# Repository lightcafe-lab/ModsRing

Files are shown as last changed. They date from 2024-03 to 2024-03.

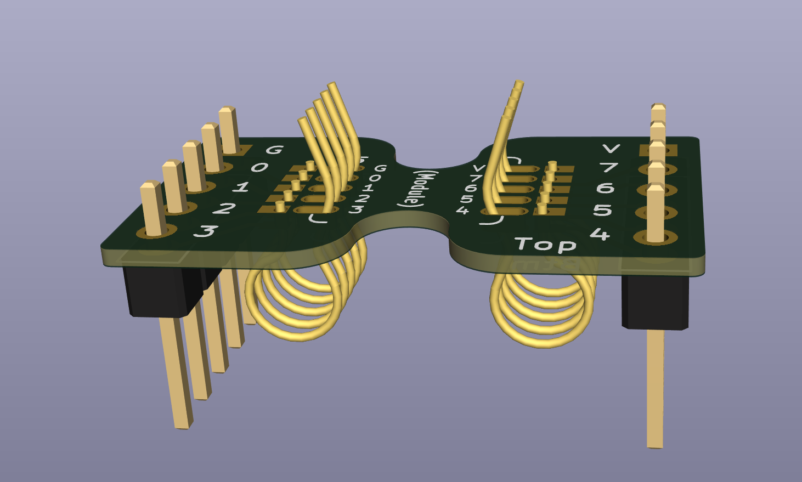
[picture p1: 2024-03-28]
smdMod/options/127to254-pitch-convert/images.png

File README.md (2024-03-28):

# ModsRing
ModsRingは**smdMod**を使用したモジュール式のスマートリングです<br>
**smdMod** = **S**urface **M**ount **D**evice **Mod**ule（表面実装式の基板モジュール）の略称です<br><br>
LIGHTCAFE LAB ModsRing 作品ページ<br>
https://lab.lightcafe.co.jp/work/modsring<br>
LIGHTCAFE LAB smdMod 作品ページ<br>
https://lab.lightcafe.co.jp/work/smdmod<br>

MODSRING
## firmware
ModsRingに書き込むArduinoのサンプルスケッチです<br>

*ble-finger-mouse*<br>
PCとBluetooth接続すると指マウスになります<br>
## hardware
ModsRing付属のハードウェアです<br>

*modsring.stl*<br>
リング形状のカバーです。22号リング(内径:20ｍｍ)のサイズになっています<br>
市販の3Dプリンタで作成できます<br>

## smdMod
KiCad (v6.0.10)を使用した回路図と基板図です<br>

*base-board/mr-base*<br>
ModsRingのベース基板です<br>

*modules/mcu-and-power*<br>
MCUと電源モジュール<br>
・MCUモジュール：ISP1807(nRF52840）をBGAピッチ（1.00mmピッチ、Φ0.6mm）に変換<br>
・電源モジュール1：3.3Vレギュレータ+LiPo充電+LiPo/USB電源切替<br>
・電源モジュール2：LiPoバッテリゲージ+LiPo電池接続パッド<br>

*modules/switch-led-and-accel-sensor*<br>
GPIOとセンサモジュール<br>
・拡張モジュール1（フルカラーLED＋スイッチ）<br>
・拡張モジュール2（加速度センサ）<br>

*modules/usb-interface*<br>
USB I/F用の基板<br>
・基板1（USB-C）<br>
・基板2（USBピン）<br>

*options/127to254-pitch-convert*<br>
モジュールのピッチ変換基板<br>
・1.27mmピッチ_10ピンを2.54mmピッチ_10ピンに変換します<br>

## ライセンスについて
この 作品 は <a rel="license" href="https://creativecommons.org/licenses/by-sa/4.0/deed.ja">クリエイティブ・コモンズ 表示 - 継承 4.0 国際 ライセンス</a>の下に提供されています<br>
<br />

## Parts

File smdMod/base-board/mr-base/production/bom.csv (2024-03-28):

Designator | Footprint | Quantity | Value | LCSC Part #
J1 | if-8080-mcu-v1-for-board | 1 | bga_foot_8*8_1mm_pitch
J2 | pad_1x04_P1.27mm_usbc_mount | 1 | Conn_01x05
J3 | pad_1x04_P1.27mm | 1 | Conn_01x04
J4, J5 | if-8080-10pin-mount-free-pin | 2 | if_8080
J6, J7 | if-8080-10pin-mount-HAT | 2 | if_8080
J8 | pad_1x02_P1.27mm | 1 | Conn_01x02

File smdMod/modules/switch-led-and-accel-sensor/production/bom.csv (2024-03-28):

Designator | Footprint | Quantity | Value | LCSC Part #
C1, C3 | 0402 | 2 | 0.1uF
C2 | 0603 | 1 | 10uF
D1 | LED_APTF1616LSEEZGKQBKC | 1 | APTF1616LSEEZGKQBKC
IC1 | LIS3DH | 1 | LIS3DH
J1, J2 | hachi-8080-10pin-castle | 2 | pin_0205_CCW
R1, R5, R6, R7, R8 | 0402 | 5 | 10k
R2 | 0402 | 1 | 1k
R3, R4 | 0402 | 2 | 330
SW1 | 435151014846 | 1 | 435151014846-SW

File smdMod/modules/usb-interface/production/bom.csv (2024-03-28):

Designator | Footprint | Quantity | Value | LCSC Part #
CN1 | USB-C_PCBPLUG | 1 | CON_USB-CPCBPLUG
J1 | pad_1x04_P1.27mm_usbc | 1 | Conn_01x04
J2 | pad_1x04_P1.27mm_usbc_with_hole | 1 | Conn_01x04
PL1 | 0603 | 1 | 0ZCM0003FF2G
R3, R4 | 0402 | 2 | 5.1k

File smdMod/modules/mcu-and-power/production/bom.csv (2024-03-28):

Designator | Footprint | Quantity | Value | LCSC Part #
C1 | 402 | 1 | 0.1uF
C2, C3, C5, C6 | 201 | 4 | 2.2uF
C4 | 201 | 1 | 0.1uF
D1 | NSR05T40XV2 | 1 | NSR05T40XV2
IC1 | MAX17048G-L | 1 | MAX17048G
IC2 | MCP73832-2ACIMC | 1 | MCP73832-2ACI-MC
IC3 | MIC5514-3.3YMT-TR | 1 | MIC5514-3.3YMT-TR
IC4 | ISP1807-LR-RS | 1 | ISP1807-LR-RS
PL1 | 603 | 1 | 0ZCM0003FF2G
Q1 | SSM3j36FS | 1 | Q_PMOS_GSD
R1, R2 | 402 | 2 | 10k
R3 | 201 | 1 | 18k
R4 | 201 | 1 | 100k

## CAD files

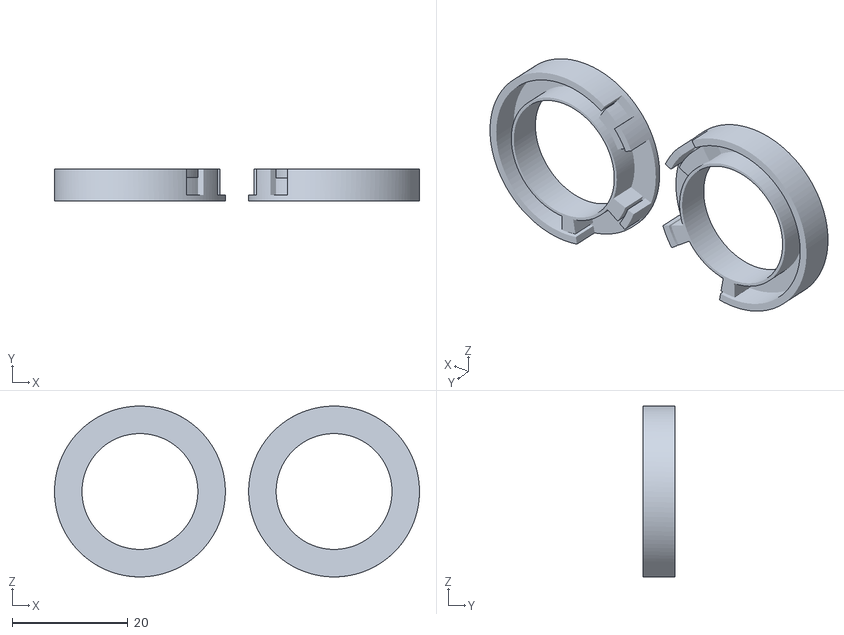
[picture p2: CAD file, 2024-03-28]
hardware/modsring.stl
63.0 x 5.51 x 29.5

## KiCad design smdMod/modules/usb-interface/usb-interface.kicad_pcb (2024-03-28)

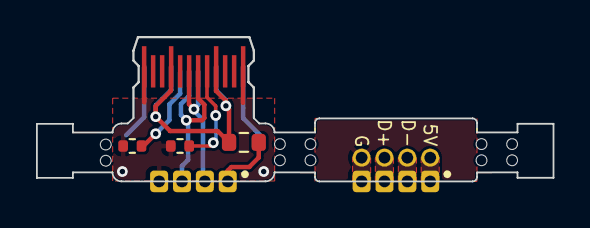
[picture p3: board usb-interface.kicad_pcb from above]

Board: 2 copper layers, 28.7 x 8.0 mm, 6 parts (1 on the bottom side), 7 nets.

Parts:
CN1: CON_USB-CPCBPLUG; USB-C_PCBPLUG
J1: Conn_01x04; pad_1x04_P1.27mm_usbc
J2: Conn_01x04; pad_1x04_P1.27mm_usbc_with_hole
PL1: 0ZCM0003FF2G; R_0603_1608Metric
R3, R4: 5.1k; R_0402_1005Metric_nosilk

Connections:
+5V: J1.1, PL1.2
/USBD+: CN1.P$A6 (D+1), CN1.P$B6 (D+2), J1.3
/USBD-: CN1.P$A7 (D-1), CN1.P$B7 (D-2), J1.2
GNDA: CN1.P$A1 (GND1), CN1.P$A12 (GND2), CN1.P$B1 (GND3), CN1.P$B12 (GND4), J1.4, R3.2, R4.2
unnamed: CN1.P$A5 (CC1), R3.1
unnamed: CN1.P$B5 (CC2), R4.1
VBUS: CN1.P$A4 (VBUS1), CN1.P$A9 (VBUS2), CN1.P$B4 (VBUS3), CN1.P$B9 (VBUS4), PL1.1

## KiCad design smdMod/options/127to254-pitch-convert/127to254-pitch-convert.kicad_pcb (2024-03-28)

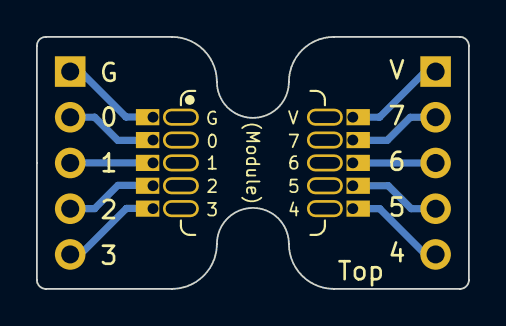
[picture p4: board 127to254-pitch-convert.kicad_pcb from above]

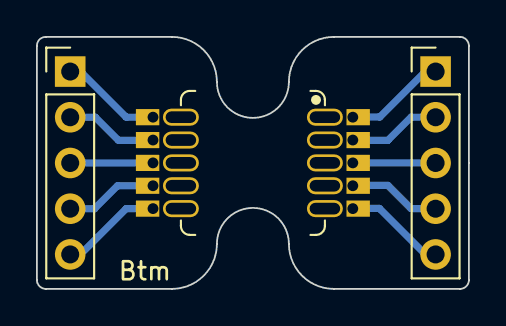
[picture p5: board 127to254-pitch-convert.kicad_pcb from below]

Board: 2 copper layers, 24.0 x 14.0 mm, 4 parts (2 on the bottom side), 10 nets.

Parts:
J1, J4: Conn_01x05_Male; PinHeader_1x05_P2.54mm_Vertical
J2: Conn_01x05_Female; FlexyPin_1x05_P1.27mm-with-line-L
J3: Conn_01x05_Female; FlexyPin_1x05_P1.27mm-with-line-R

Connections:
unnamed: J1.1, J2.1
unnamed: J1.2, J2.2
unnamed: J1.3, J2.3
unnamed: J1.4, J2.4
unnamed: J1.5, J2.5
unnamed: J3.1, J4.1
unnamed: J3.2, J4.2
unnamed: J3.3, J4.3
unnamed: J3.4, J4.4
unnamed: J3.5, J4.5

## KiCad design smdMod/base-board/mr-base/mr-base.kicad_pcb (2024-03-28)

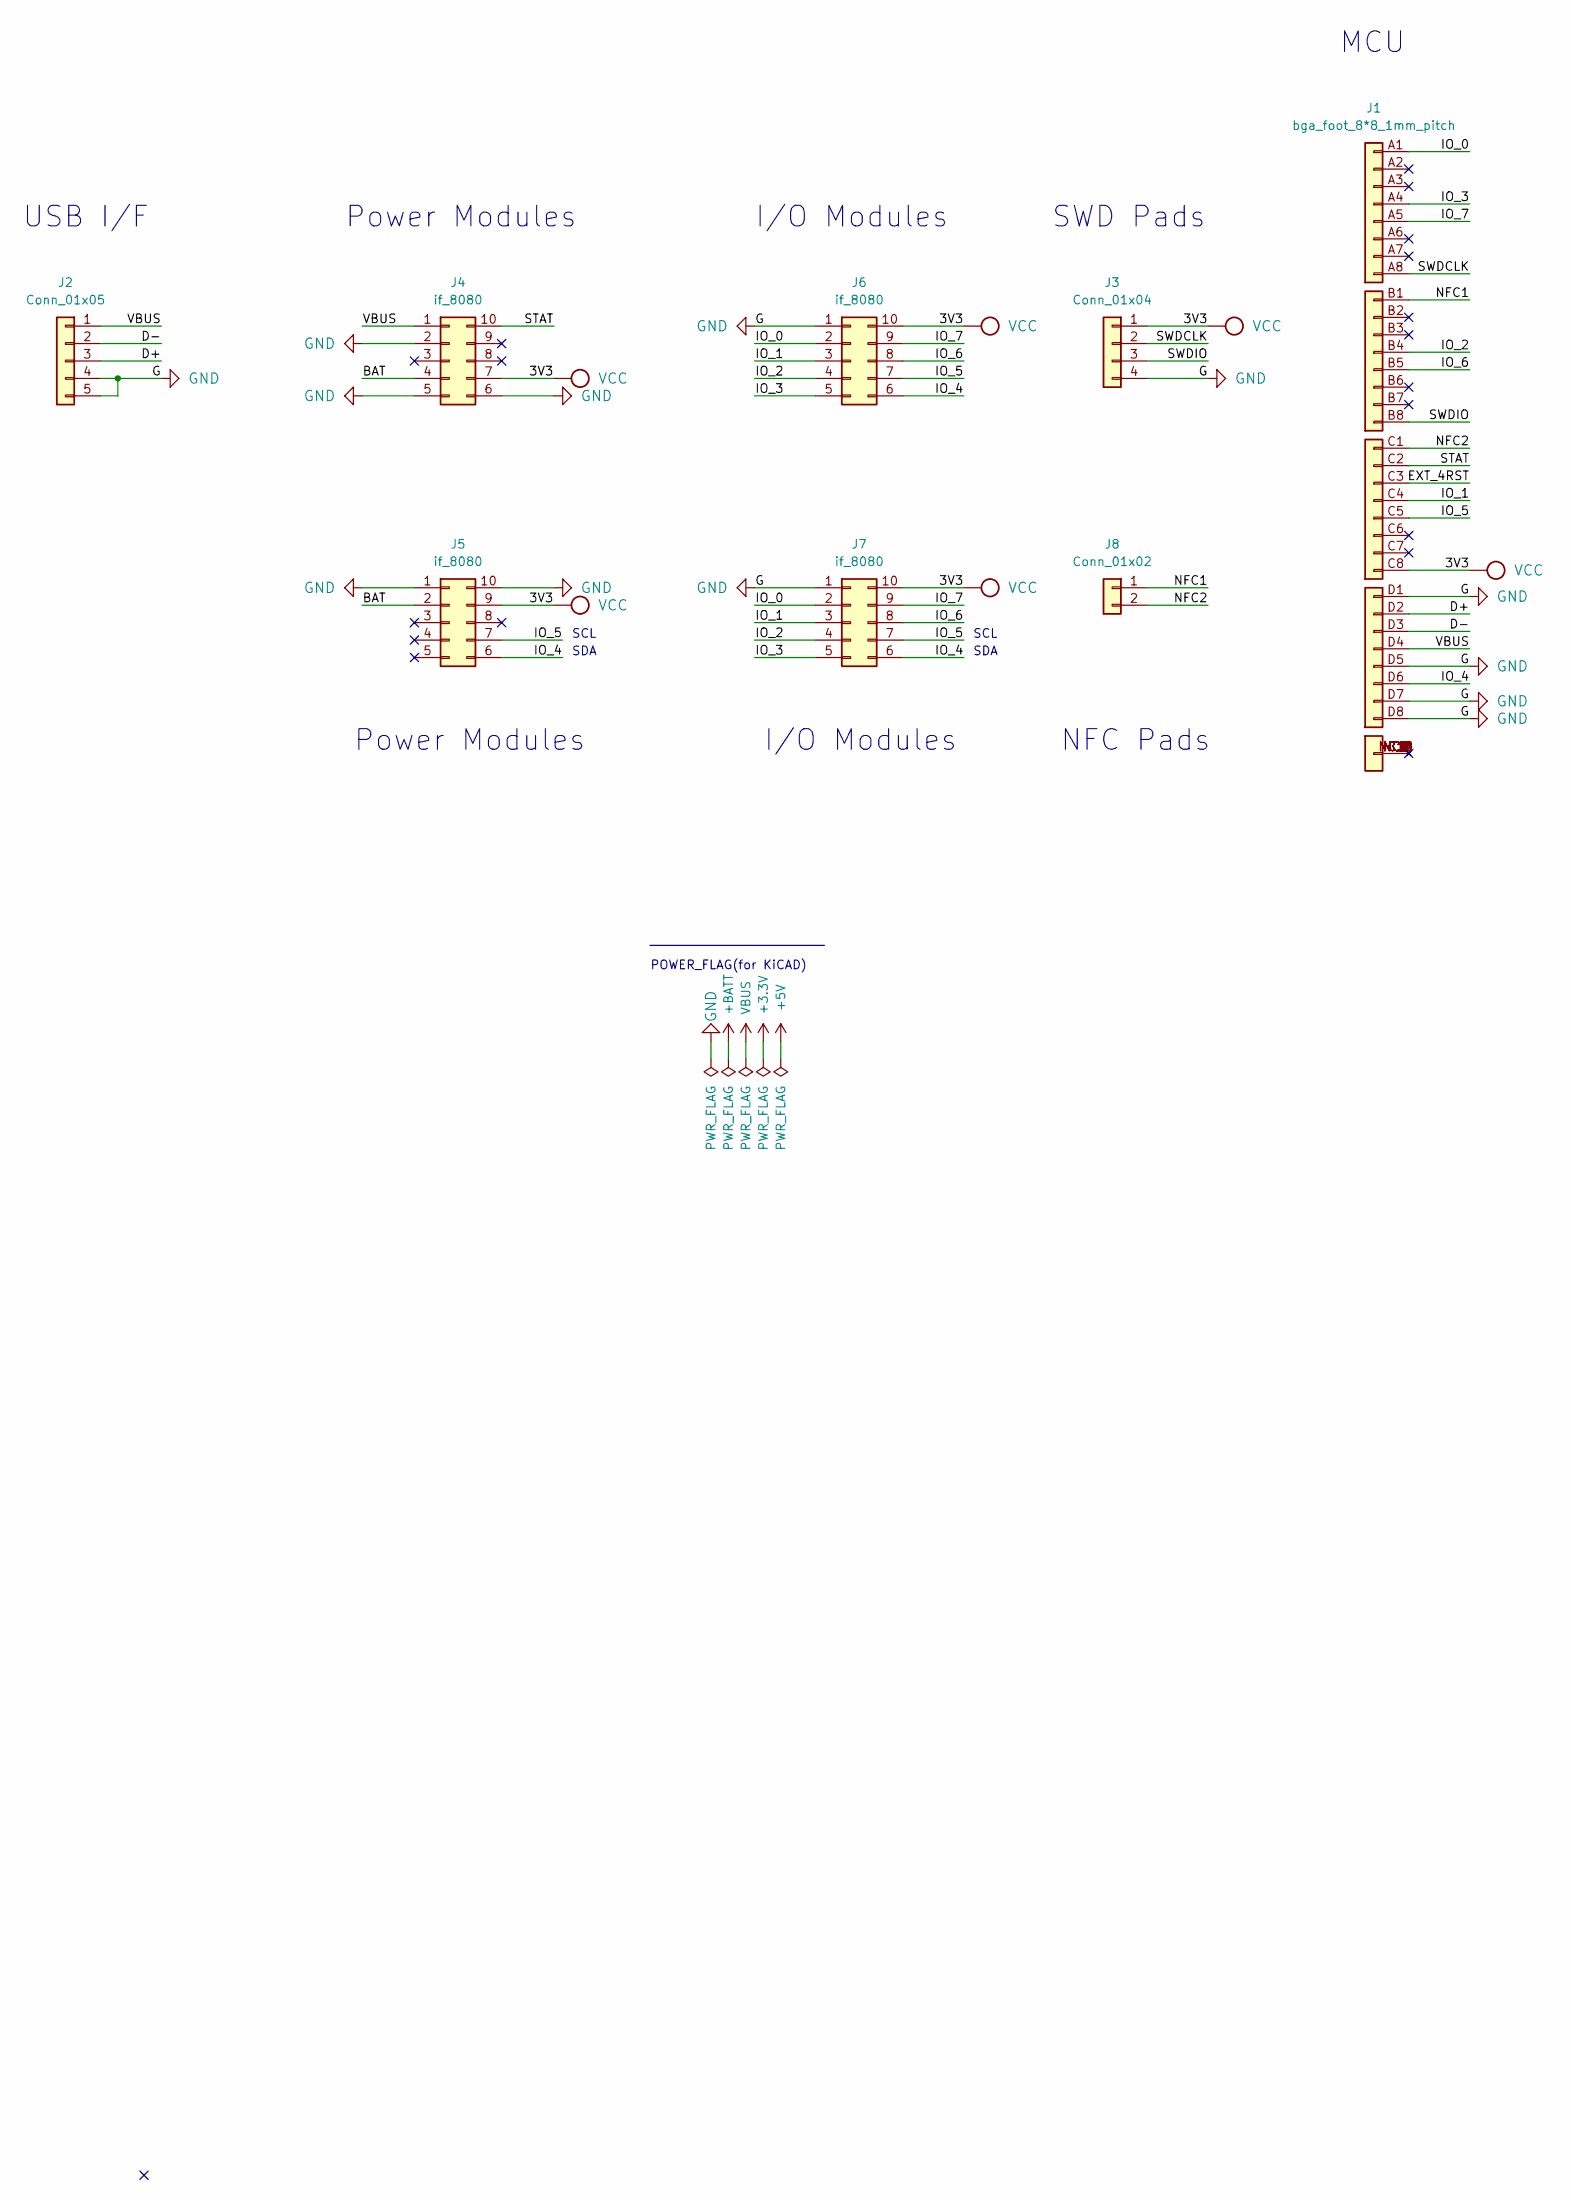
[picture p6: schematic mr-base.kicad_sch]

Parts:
J1: bga_foot_8*8_1mm_pitch; if-8080-mcu-v1-for-board
J2: Conn_01x05; pad_1x04_P1.27mm_usbc_mount
J3: Conn_01x04; pad_1x04_P1.27mm
J4, J5: if_8080; if-8080-10pin-mount-free-pin
J6, J7: if_8080; if-8080-10pin-mount-HAT
J8: Conn_01x02; pad_1x02_P1.27mm

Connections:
/BAT: J4.4, J5.2
/D+: J1.D2, J2.3
/D-: J1.D3, J2.2
/EXT_4RST: J1.C3
/IO_0: J1.A1, J6.2, J7.2
/IO_1: J1.C4, J6.3, J7.3
/IO_2: J1.B4, J6.4, J7.4
/IO_3: J1.A4, J6.5, J7.5
/IO_4: J1.D6, J5.6, J6.6, J7.6
/IO_5: J1.C5, J5.7, J6.7, J7.7
/IO_6: J1.B5, J6.8, J7.8
/IO_7: J1.A5, J6.9, J7.9
/NFC1: J1.B1, J8.1
/NFC2: J1.C1, J8.2
/STAT: J1.C2, J4.10
/SWDCLK: J1.A8, J3.2
/SWDIO: J1.B8, J3.3
GND: J1.D1, J1.D5, J1.D7, J1.D8, J2.4, J2.5, J3.4, J4.2, J4.5, J4.6, J5.1, J5.10, J6.1, J7.1
VBUS: J1.D4, J2.1, J4.1
VCC: J1.C8, J3.1, J4.7, J5.9, J6.10, J7.10

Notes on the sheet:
SWD Pads
USB I/F
SCL
I/O Modules
SDA
NFC Pads
POWER_FLAG(for KiCAD)
Power Modules
MCU

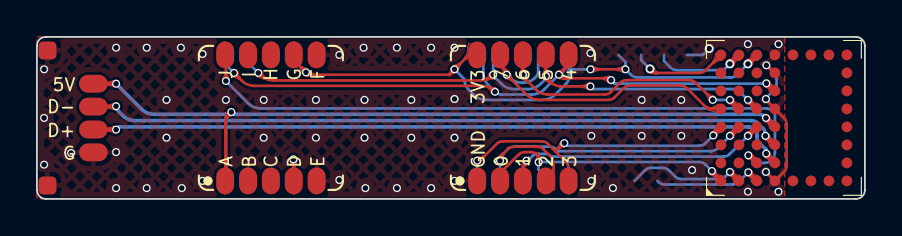
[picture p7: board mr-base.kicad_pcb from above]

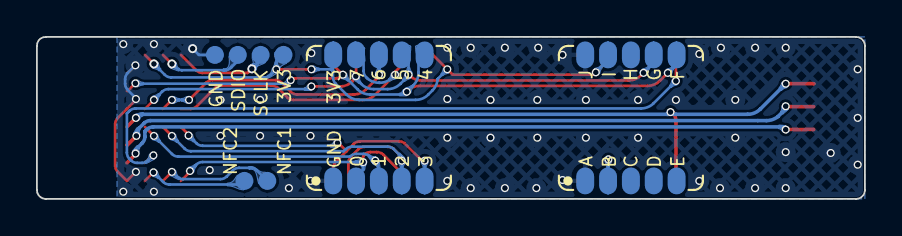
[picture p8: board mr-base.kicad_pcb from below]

Board: 2 copper layers, 46.0 x 9.0 mm, 8 parts (4 on the bottom side), 19 nets.

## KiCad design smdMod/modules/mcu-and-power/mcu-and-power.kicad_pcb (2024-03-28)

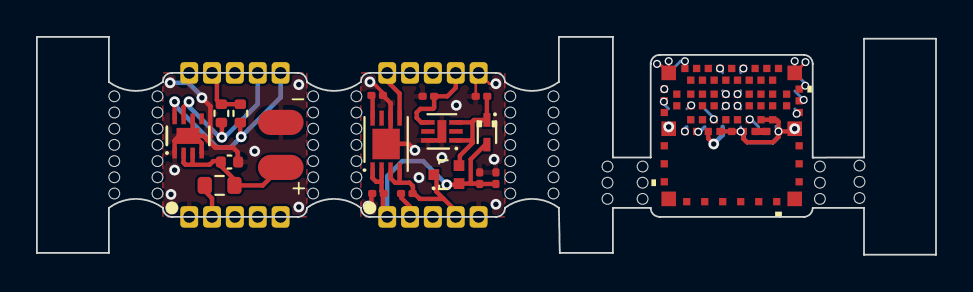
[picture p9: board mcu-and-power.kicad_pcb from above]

Board: 2 copper layers, 49.9 x 12.1 mm, 21 parts (0 on the bottom side), 33 nets.

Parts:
C1: 0.1uF; C_0402_1005Metric_nosilk
C2, C3, C5, C6: 2.2uF; C_0201_0603Metric_nosilk
C4: 0.1uF; C_0201_0603Metric_nosilk
D1: NSR05T40XV2
IC1: MAX17048G; MAX17048G-L
IC2: MCP73832-2ACI-MC; MCP73832-2ACIMC
IC3: MIC5514-3.3YMT-TR
IC4: ISP1807-LR-RS
J1: Conn_01x02_Male; 1×02_pinhead_smd
J2, J3: if_8080; if-8080-10pin-castle-v1
J4: bga_foot_8*8_1mm_pitch; if-8080-mcu-v1
PL1: 0ZCM0003FF2G; R_0603_1608Metric
Q1: Q_PMOS_GSD; SSM3j36FS
R1, R2: 10k; R_0402_1005Metric_nosilk
R3: 18k; R_0201_0603Metric_nosilk
R4: 100k; R_0201_0603Metric_nosilk

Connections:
/3V3_A: J2.9, R1.2, R2.2
/3V3_B: C6.1, IC3.4 (VOUT), J3.7
/BAT_A: J2.2, PL1.2
/BAT_B: C3.1, IC2.3 (VBAT), IC2.4 (VBAT), J3.4, Q1.3 (D)
/D+: IC4.8 (D+), J4.D2
/D-: IC4.10 (D-), J4.D3
/EXT_4RST: IC4.13 (P0_18_RESET), J4.C3
/IO_0: IC4.48 (P0_28_AIN4), J4.A1
/IO_1: IC4.61 (P1_11), J4.C4
/IO_2: IC4.53 (P1_13), J4.B4
/IO_3: IC4.42 (P0_31_AIN7), J4.A4
/IO_4: IC4.19 (P0_24), J4.D6
/IO_5: IC4.60 (P1_10), J4.C5
/IO_6: IC4.52 (P1_14), J4.B5
/IO_7: IC4.38 (P0_03_AIN1), J4.A5
/LIPO_IN: C1.1, IC1.2 (CELL), IC1.3 (Vdd), J1.1, PL1.1
/NFC1: IC4.2 (P0_09_NFC1), J4.B1
/NFC2: IC4.4 (P0_10_NFC2), J4.C1
/SCL: IC1.7 (SCL), J2.7, R1.1
/SDA: IC1.8 (SDA), J2.6, R2.1
/STAT: IC4.64 (P1_01), J4.C2
/STAT_B: IC2.5 (STAT), J3.10
/SWDCLK: IC4.30 (SWDCLK), J4.A8
/SWDIO: IC4.28 (SWDIO), J4.B8
/USB5V: C2.1, C4.1, D1.2 (A), IC2.1 (VDD), IC2.2 (VDD), J3.1, Q1.1 (G), R4.2
GND: IC4.1 (VSS), IC4.7 (VSS), IC4.14 (VSS), IC4.16 (VSS), IC4.18 (VSS), IC4.21 (VSS), IC4.23 (VSS), IC4.24 (VSS), IC4.25 (VSS), IC4.31 (VSS), J4.D1, J4.D5, J4.D7, J4.D8
GNDA: C1.2, IC1.1 (CTG), IC1.4 (GND), IC1.6 (QSTRT), IC1.9 (EP), J1.2, J2.1, J2.10
GNDB: C2.2, C3.2, C4.2, C5.2, C6.2, IC2.6 (Vss), IC2.9 (EP), IC3.6 (GND), IC3.7 (EP), J3.2, J3.5, J3.6, R3.2, R4.1
unnamed: C5.1, D1.1 (K), IC3.1 (EN), IC3.3 (VIN), Q1.2 (S)
unnamed: IC2.8 (PROG), R3.1
unnamed: IC4.20 (OUT_ANT), IC4.22 (OUT_MOD)
VBUS: IC4.12 (VBUS), J4.D4
VCC: IC4.26 (VCC_NRF), J4.C8

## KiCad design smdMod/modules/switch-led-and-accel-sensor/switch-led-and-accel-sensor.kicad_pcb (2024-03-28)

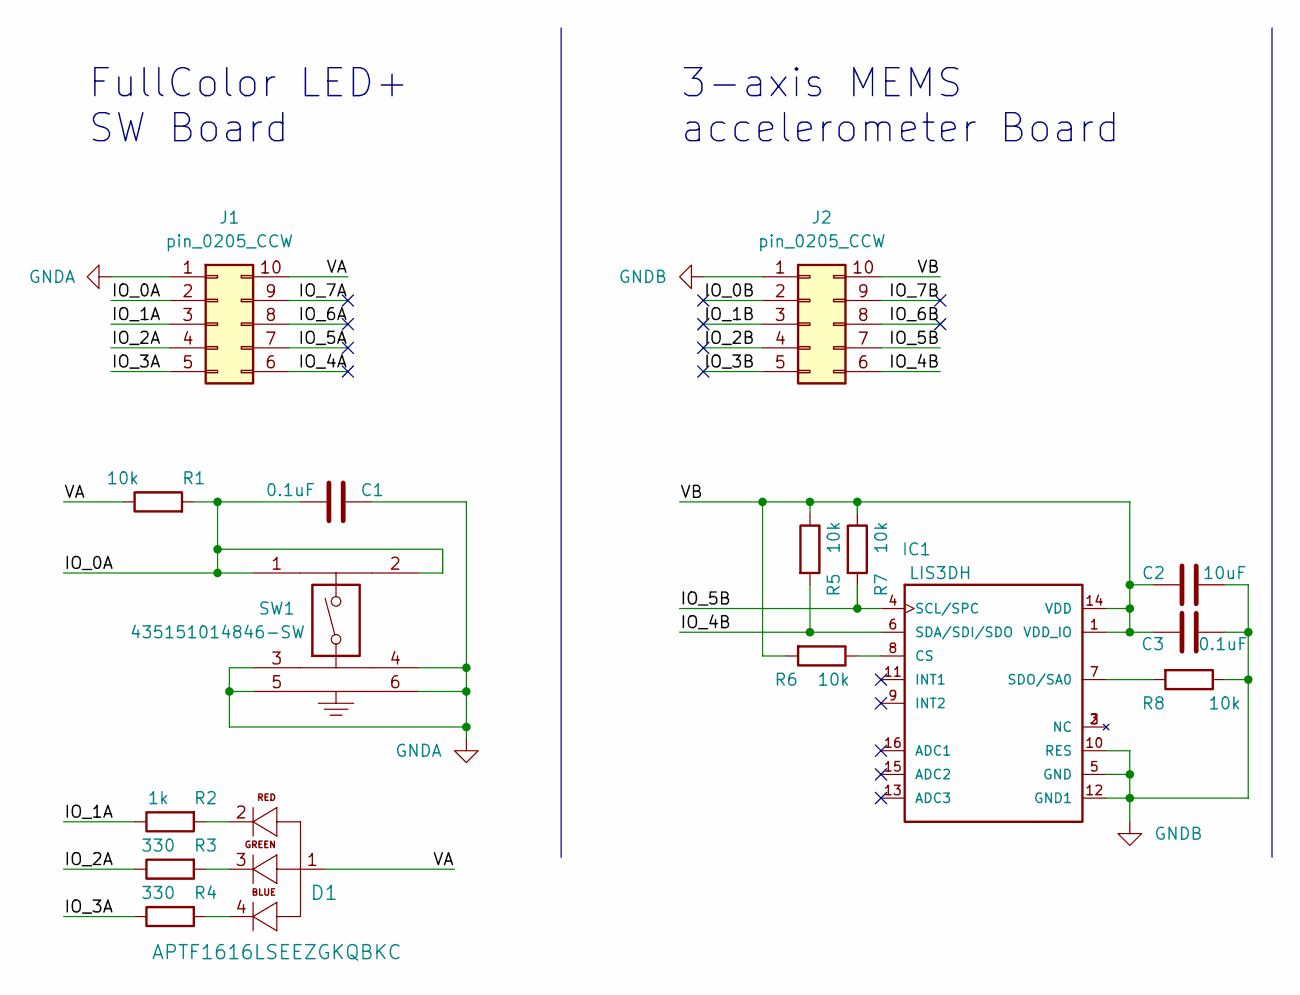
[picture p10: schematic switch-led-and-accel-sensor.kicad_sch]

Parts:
C1, C3: 0.1uF; C_0402_1005Metric
C2: 10uF; C_0603_1608Metric
D1: APTF1616LSEEZGKQBKC; LED_APTF1616LSEEZGKQBKC
IC1: LIS3DH
J1, J2: pin_0205_CCW; hachi-8080-10pin-castle
R1, R5, R6, R7, R8: 10k; R_0402_1005Metric
R2: 1k; R_0402_1005Metric
R3, R4: 330; R_0402_1005Metric
SW1: 435151014846-SW; 435151014846

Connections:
/IO_0A: C1.2, J1.2, R1.2, SW1.1, SW1.2
/IO_0B: J2.2
/IO_1A: J1.3, R2.1
/IO_1B: J2.3
/IO_2A: J1.4, R3.1
/IO_2B: J2.4
/IO_3A: J1.5, R4.1
/IO_3B: J2.5
/IO_4A: J1.6
/IO_4B: IC1.6 (SDA/SDI/SDO), J2.6, R5.2
/IO_5A: J1.7
/IO_5B: IC1.4 (SCL/SPC), J2.7, R7.2
/IO_6A: J1.8
/IO_6B: J2.8
/IO_7A: J1.9
/IO_7B: J2.9
/VA: D1.1, J1.10, R1.1
/VB: C2.1, C3.1, IC1.1 (VDD_IO), IC1.14 (VDD), J2.10, R5.1, R6.2, R7.1
GNDA: C1.1, J1.1, SW1.3, SW1.4, SW1.5, SW1.6
GNDB: C2.2, C3.2, IC1.5 (GND), IC1.10 (RES), IC1.12 (GND1), J2.1, R8.1
unnamed: D1.2, R2.2
unnamed: D1.3, R3.2
unnamed: D1.4, R4.2
unnamed: IC1.7 (SDO/SA0), R8.2
unnamed: IC1.8 (CS), R6.1

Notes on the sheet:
3-axis MEMS accelerometer Board
FullColor LED+ SW Board

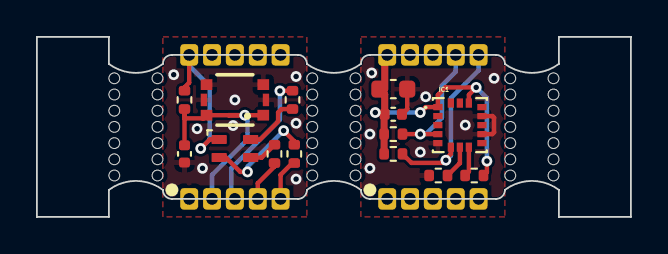
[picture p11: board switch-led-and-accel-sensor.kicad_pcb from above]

Board: 2 copper layers, 33.0 x 10.0 mm, 16 parts (0 on the bottom side), 15 nets.

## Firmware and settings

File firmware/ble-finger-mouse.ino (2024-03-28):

/*********************************************************************
 This is an example for our nRF52 based Bluefruit LE modules

 Pick one up today in the adafruit shop!

 Adafruit invests time and resources providing this open source code,
 please support Adafruit and open-source hardware by purchasing
 products from Adafruit!

 MIT license, check LICENSE for more information
 All text above, and the splash screen below must be included in
 any redistribution
*********************************************************************/
#include <bluefruit.h>
#include "SparkFunLIS3DH.h"
#include "Wire.h"

BLEDis bledis;
BLEHidAdafruit blehid;

const int buttonPin = 0;     // the number of the pushbutton pin
const int ledPin =  1;      // the number of the LED pin
#define MOVE_STEP      10
#define MOVE_THRD_X    0.5 //0~1.0
#define MOVE_THRD_Y    0.4 //0~1.0

#define MOVE_MULT    17
LIS3DH myIMU; //Default constructor is I2C, addr 0x19.

int buttonState = 0;         // variable for reading the pushbutton status
bool buttonFlag =false;
double moveX=0;
double moveY=0;

void setup() 
{
  pinMode(buttonPin, INPUT);
  pinMode(ledPin, OUTPUT);
  
  Bluefruit.begin();
  // HID Device can have a min connection interval of 9*1.25 = 11.25 ms
  Bluefruit.Periph.setConnInterval(9, 16); // min = 9*1.25=11.25 ms, max = 16*1.25=20ms
  Bluefruit.setTxPower(4);    // Check bluefruit.h for supported values

  // Configure and Start Device Information Service
  bledis.setManufacturer("LIGHTCAFE LAB");
  bledis.setModel("ModsRing nRF52840");
  bledis.begin();

  // BLE HID
  blehid.begin();

  // Set up and start advertising
  startAdv();

  myIMU.begin();
}

void startAdv(void)
{  
  // Advertising packet
  Bluefruit.Advertising.addFlags(BLE_GAP_ADV_FLAGS_LE_ONLY_GENERAL_DISC_MODE);
  Bluefruit.Advertising.addTxPower();
  Bluefruit.Advertising.addAppearance(BLE_APPEARANCE_HID_MOUSE);
  
  // Include BLE HID service
  Bluefruit.Advertising.addService(blehid);

  // There is enough room for 'Name' in the advertising packet
  Bluefruit.Advertising.addName();
  
  /* Start Advertising
   * - Enable auto advertising if disconnected
   * - Interval:  fast mode = 20 ms, slow mode = 152.5 ms
   * - Timeout for fast mode is 30 seconds
   * - Start(timeout) with timeout = 0 will advertise forever (until connected)
   * 
   * For recommended advertising interval
   * https://developer.apple.com/library/content/qa/qa1931/_index.html   
   */
  Bluefruit.Advertising.restartOnDisconnect(true);
  Bluefruit.Advertising.setInterval(32, 244);    // in unit of 0.625 ms
  Bluefruit.Advertising.setFastTimeout(30);      // number of seconds in fast mode
  Bluefruit.Advertising.start(0);                // 0 = Don't stop advertising after n seconds  
}

void loop() 
{    
  delay(5);
  
  moveY=myIMU.readFloatAccelY();
  if(moveY<-MOVE_THRD_Y){
    //up
    moveY=moveY*MOVE_MULT;
  }
  if(moveY>MOVE_THRD_Y){
    //down
    moveY=moveY*MOVE_MULT;
  }
  moveX=myIMU.readFloatAccelX();
  if(moveX<-MOVE_THRD_X){
    //left
    moveX=moveX*MOVE_MULT;
  }
  if(moveX>MOVE_THRD_X){
    //right
    moveX=moveX*MOVE_MULT;
  }
  blehid.mouseMove(moveX, -moveY);

}

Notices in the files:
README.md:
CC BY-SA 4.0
